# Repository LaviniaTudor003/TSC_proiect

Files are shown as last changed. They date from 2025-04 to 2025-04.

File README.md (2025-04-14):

# e-book reader



# BOM (Bill Of Materials)

| Component | Supplier Link | Datasheet |
|---|---|---|
| 744043680 | [Model](https://ro.mouser.com/ProductDetail/Wurth-Elektronik/744043680?qs=PGXP4M47uW6VkZq%252BkzjrHA%3D%3D) | [Datasheet](https://www.we-online.com/components/products/datasheet/744043680.pdf) |
| BD5229G-TR | [Model](https://www.digikey.ee/en/models/658502) | [Datasheet](https://www.rohm.com/datasheet?p=BD5229G&dist=Digi-key&media=referral&source=digi-key.com&campaign=Digi-key) |
| Capacitor 0402 | [Model](https://componentsearchengine.com/part-view/CC0402MRX5R5BB106/YAGEO) | [Datasheet](https://componentsearchengine.com/Datasheets/2/CC0402MRX5R5BB106.pdf) |
| CPH3225A | [Model](https://www.snapeda.com/parts/CPH3225A/Seiko+Instruments/view-part/?ref=eda) | [Datasheet](https://www.snapeda.com/parts/CPH3225A/Seiko%20Instruments/datasheet/) |
| Custom Button | [Model](https://industry.panasonic.com/global/en/products/control/switch/light-touch/number/evqpuj02k) | [Datasheet](https://industry.panasonic.com/global/en/downloads?tab=catalog&small_g_cd=203&part_no=EVQPUJ02K) |
| MBR0530 Schottky Diode | [Model](https://www.snapeda.com/parts/MBR0530/Onsemi/view-part/?ref=eda) | [Datasheet](https://www.snapeda.com/parts/MBR0530/ON%20Semiconductor/datasheet/) |
| PGB1010603MR | [Model](https://www.snapeda.com/parts/PGB1010603MR/Littelfuse/view-part/?ref=eda) | [Datasheet](https://www.snapeda.com/parts/PGB1010603MR/Littelfuse%20Inc./datasheet/) |
| QWIIC Connector | [Model](https://www.snapeda.com/parts/PRT-14417/SparkFun/view-part/) | [Datasheet](https://www.snapeda.com/parts/PRT-14417/SparkFun%20Electronics/datasheet/) |
| USB4110-GF-A | [Model](https://componentsearchengine.com/part-view/USB4110-GF-A/GCT%20(GLOBAL%20CONNECTOR%20TECHNOLOGY)) | [Datasheet](https://gct.co/files/drawings/usb4110.pdf) |
| USBLC6-2SC6Y | [Model](https://www.snapeda.com/parts/USBLC6-2SC6Y/STMicroelectronics/view-part/?ref=eda) | [Datasheet](https://www.snapeda.com/parts/USBLC6-2SC6Y/STMicroelectronics/datasheet/) |
| W25Q512JVEIQ | [Model](https://www.digikey.ro/en/models/10244706) | [Datasheet](https://www.winbond.com/resource-files/W25Q512JV%20SPI%20RevB%2006252019%20KMS.pdf) |
| RCL CPOL 3528 | [Model](https://www.snapeda.com/parts/TAJB475K025RNJ/AVX/view-part/?ref=dk&t=capacitor%203528&con_ref=None) | [Datasheet](https://s3.amazonaws.com/snapeda/datasheet/TAJB475K025RNJ_AVX.pdf) |
| DS3231SN | [Model](https://www.snapeda.com/parts/DS3231SN%23/Analog+Devices/view-part/?ref=eda) | [Datasheet](https://www.snapeda.com/parts/DS3231SN%23/Analog%20Devices/datasheet/) |
| ESP32 WROVER 0805 Capacitor  | [Model](https://ro.mouser.com/ProductDetail/KYOCERA-AVX/SD0805S020S1R0?qs=jCA%252BPfw4LHbpkAoSnwrdjw%3D%3D) | [Datasheet](https://ro.mouser.com/datasheet/2/40/schottky-3165252.pdf) |
| ESP32 WROVER BME680 Sensor | [Model](https://www.digikey.ro/en/models/7401317) | [Datasheet](https://www.bosch-sensortec.com/media/boschsensortec/downloads/datasheets/bst-bme680-ds001.pdf) |
| ESP32 WROVER MCP73831 Power Management | [Model](https://www.snapeda.com/parts/MCP73831T-2ACI/OT/Microchip/view-part/) | [Datasheet](https://www.snapeda.com/parts/MCP73831T-2ACI/OT/Microchip/datasheet/) |
| ESP32C6 Varistor 1812 | [Model](https://www.snapeda.com/parts/RC0603JR-070RL/Yageo/view-part/) | [Datasheet](https://www.snapeda.com/parts/RC0603JR-070RL/Yageo/datasheet/) |
| ESP32C6 WROOM-1-N8 | [Model](https://www.snapeda.com/parts/ESP32-C6-WROOM-1-N8/Espressif+Systems/view-part/?ref=eda) | [Datasheet](https://www.snapeda.com/parts/ESP32-C6-WROOM-1-N8/Espressif%20Systems/datasheet/) |
| FH34SRJ-24S-0.5SH | [Model](https://www.snapeda.com/parts/FH34SRJ-24S-0.5SH(99)/Hirose/view-part/) | [Datasheet](https://www.snapeda.com/parts/FH34SRJ-24S-0.5SH(99)/Hirose%20Connector/datasheet/) |
| LED Chip 0603 | [Model](https://grabcad.com/library/0603-smd-led-1) | [Datasheet](https://www.snapeda.com/parts/KP-1608SURCK/Kingbright/datasheet/) |
| MAX17048G+T10 | [Model](https://www.snapeda.com/parts/MAX17048G+T10/Analog+Devices/view-part/?ref=eda) | [Datasheet](https://www.snapeda.com/parts/MAX17048G+T10/Analog%20Devices/datasheet/) |
| Resistor 0402 | [Model](https://componentsearchengine.com/part-view/R0402%201%25%20100%20K%20(RC0402FR-07100KL)/YAGEO) | [Datasheet](https://www.yageo.com/upload/media/product/products/datasheet/rchip/PYu-RC_Group_51_RoHS_L_12.pdf) |
| 112A-TAAR-R03 | [Model](https://www.snapeda.com/parts/112A-TAAR-R03/Attend/view-part/) | [Datasheet](https://www.snapeda.com/parts/112A-TAAR-R03/Attend/datasheet/) |
| SI1308EDL-T1-GE3 MOSFET | [Model](https://www.snapeda.com/parts/SI1308EDL-T1-GE3/Vishay+Siliconix/view-part/?ref=eda) | [Datasheet](https://www.snapeda.com/parts/SI1308EDL-T1-GE3/Vishay%20Siliconix/datasheet/) |
| SJ | [Model](https://grabcad.com/library/solder-jumpers-1) | [Datasheet](https://github.com/TeodorStamatin/EBook_Reader/tree/main) |
| XC6220A331MR-G | [Model](https://componentsearchengine.com/part-view/XC6220A331MR-G/Torex) | [Datasheet](https://product.torexsemi.com/system/files/series/xc6220.pdf) |

# Conexiuni și module hardware utilizate:
•	USB-C Connector + ESD Protection
-	Intrare principală de alimentare și programare.
•	LDO Voltage Regulator
-	Reglează tensiunea de intrare la 3.3V stabil pentru alimentarea ESP32 și altor componente.
•	Li-Po Battery Charging Controller
-	Încarcă un acumulator Li-Po de la 5V (USB)
•	ESP32-C6
-	Microcontroller principal - responsabil de control, procesare si comunicare
•	E-Paper Drive Circuit
-	Oferă semnalul de putere necesar pentru activarea e-paper-ului
•	Display Type Selector
-	Permite comutarea
•	Voltage Supervisor + Reset
-	Asigură resetul corect la pornire
Poziționarea componentelor a fost gândită pentru:
•	acces facil la butoane,
•	vizibilitatea e-paper-ului,
•	montarea sigură a bateriei cu suport mecanic.
(pe baza schemei si recomandarilor primite)

# Functionalitate Hardware:
**Componente, Module și Senzori**
**Alimentare și Management Energie**
 Conector USB-C + Protecție ESD
 Funcție: Asigură alimentarea principală a sistemului și protejează împotriva descărcărilor electrostatice.
 
 Controler Încărcare Baterie – MCP73831
 Funcție: Gestionează încărcarea bateriei Li-Po, controlează curentul de încărcare.
 
 Baterie Li-Po
 Funcție: Sursă de alimentare secundară pentru funcționare autonomă (fără USB).
 
 Regulator de Tensiune LDO (3.3V)
 Funcție: Stabilizează tensiunea de alimentare pentru microcontroler și restul componentelor.
 
 Supervizor Tensiune + Buton Reset/Boot
 Funcție: Monitorizează nivelul tensiunii de alimentare și permite resetarea sau intrarea în modul boot al ESP32-C6.

**Control și Procesare:**
 ESP32-C6-WROOM-1-N8
 Funcție: Microcontroler principal. Gestionează comunicațiile (SPI, I2C, UART), interacțiunea cu senzorii și controlul perifericelor. Oferă conectivitate Wi-Fi și Bluetooth Low Energy.
 
 Memorie Externă NOR Flash – 64MB
 Funcție: Stocare extinsă pentru firmware și date.
 Interfață: SPI.

**Timp Real:**
 Modul RTC – DS3231SN
 Funcție: Ceas de timp real de înaltă precizie, cu suport pentru alarmă și funcționare pe baterie de backup.
 Interfață: I2C.

**Senzori de Mediu:**
 BME688 – Senzor ambiental
 Funcție: Măsoară temperatura, umiditatea, presiunea atmosferică și compușii organici volatili (VOC).
 Interfață: I2C (Qwiic / Stemma QT pentru conectare rapidă).
 Consum: Standby ultra-low power, activ ~3.1 mA.

**Afișaj:**
 Circuit de control pentru ecran E-Paper + Header de conectare
 Funcție: Generează semnalele necesare pentru funcționarea ecranelor E-Paper.
 Interfață: SPI cu linii de control dedicate (Busy, Reset, DC, CS).

**Stocare locală:**
 Slot Card microSD
 Funcție: Permite salvarea datelor local (loguri, configurări, fișiere).
 Interfață: SPI, cu semnal Chip Select dedicat.

**Interfețe de Comunicație:**
 I2C: Utilizat pentru BME688 și DS3231SN.
 SPI: Utilizat pentru NOR Flash, E-Paper Display și Card SD.
 UART: Disponibil pentru debug sau extensii opționale.
 Wi-Fi & Bluetooth LE: Oferite de modulul ESP32-C6.
# Pini ESP32-C6

| Componenta / Rol | Pin ESP32-C6 | Motivație |
|---|---|---|
| I2C SDA către BME688 și DS3231SN | IO14 (SDA) | Transmite date între microcontroler și dispozitivele I2C. |
| I2C SCL către BME688 și DS3231SN | IO15 (SCL) | Coordonează sincronizarea comunicării I2C. |
| SPI MOSI către NOR Flash, E-Paper, SD Card | IO6 (MOSI) | Trimite informații din ESP32 către perifericele conectate pe SPI. |
| SPI MISO din NOR Flash, E-Paper, SD Card | IO7 (MISO) | Primește date înapoi de la dispozitivele SPI. |
| SPI Clock | IO8 (SCK) | Oferă impulsurile de sincronizare pentru magistrala SPI. |
| Chip Select NOR Flash | IO9 (CS1) | Activează memoria NOR atunci când este utilizată. |
| Chip Select E-Paper Display | IO10 (CS2) | Selectează modulul de afișaj E-Paper pentru transmiterea de date. |
| Chip Select SD Card | IO11 (CS3) | Indică faptul că SD Card-ul este dispozitivul activ pe SPI. |
| UART RX, TX (debug) | IO16, IO17 | Permite trimiterea și recepționarea datelor pentru depanare și upload firmware. |
| Reset / Boot control | IO21 | Folosit pentru repornirea manuală a sistemului sau inițierea modului de programare. |

# PCB_2D:



# PCB_3D:
 


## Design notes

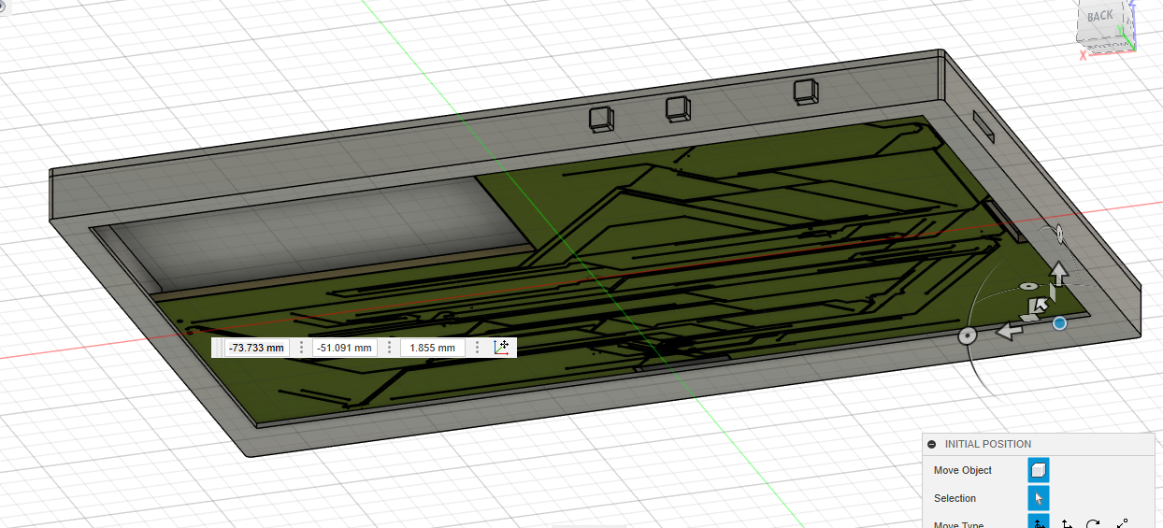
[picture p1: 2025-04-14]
Images/Screenshot 2025-04-14 131702.png

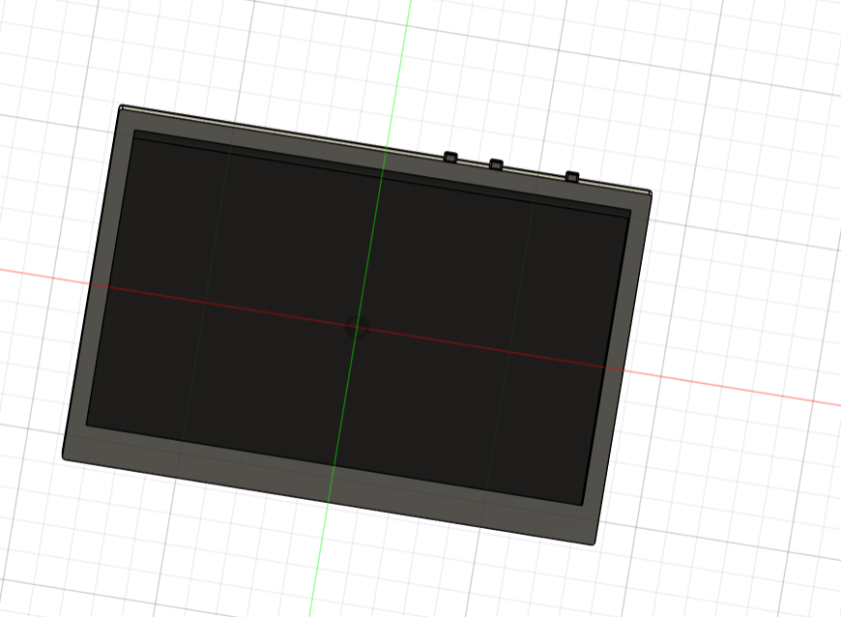
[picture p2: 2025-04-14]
Images/Screenshot 2025-04-14 134810.png

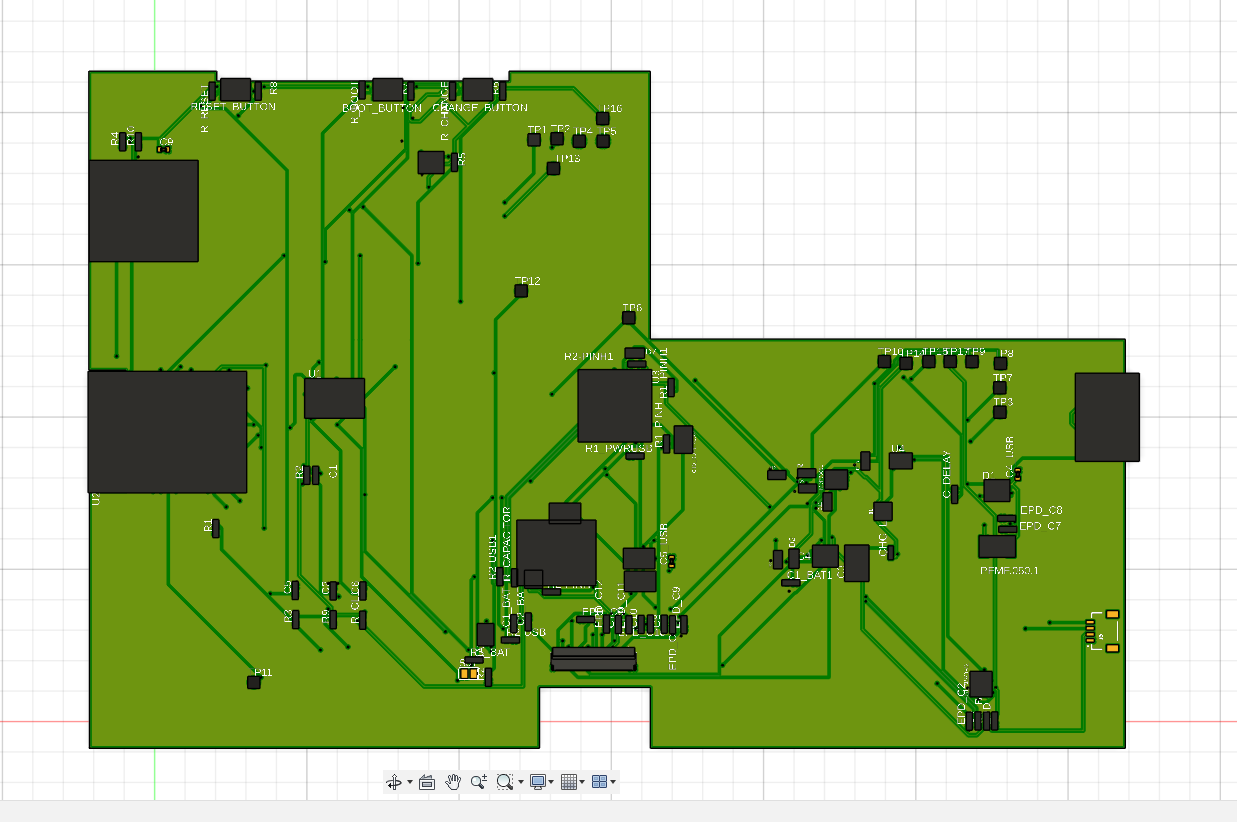
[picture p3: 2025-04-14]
Images/Screenshot 2025-04-14 090113.png

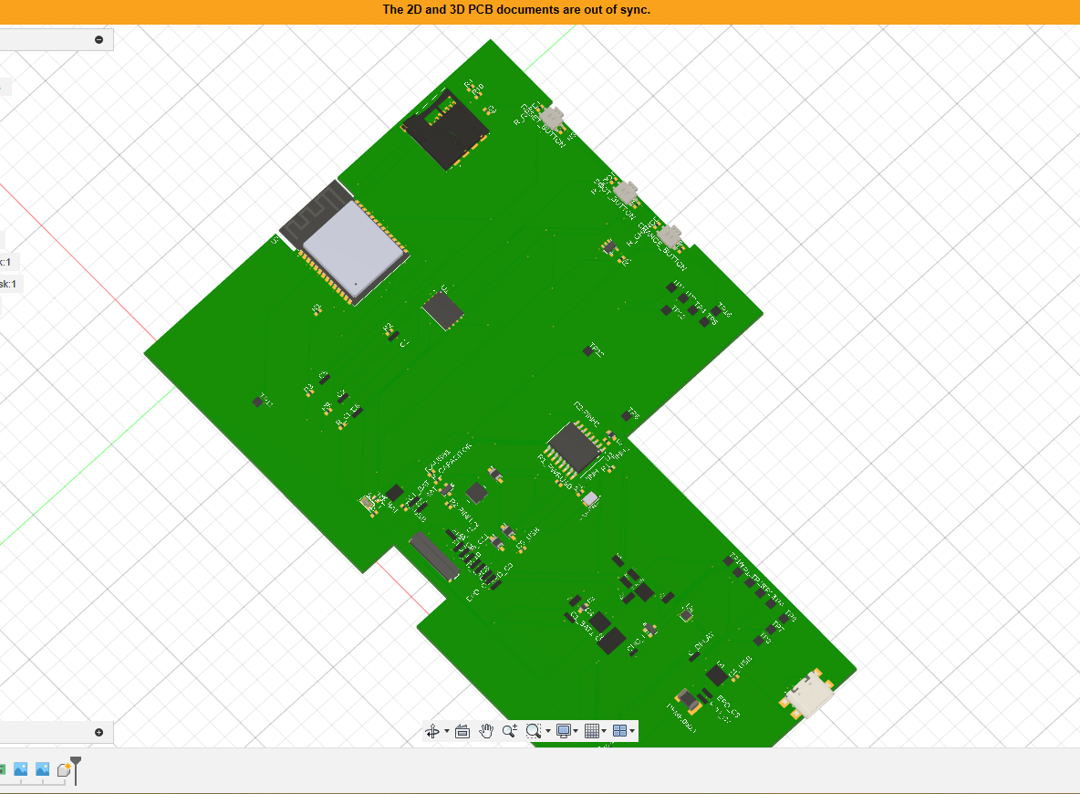
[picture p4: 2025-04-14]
Images/Screenshot 2025-04-14 125641.png

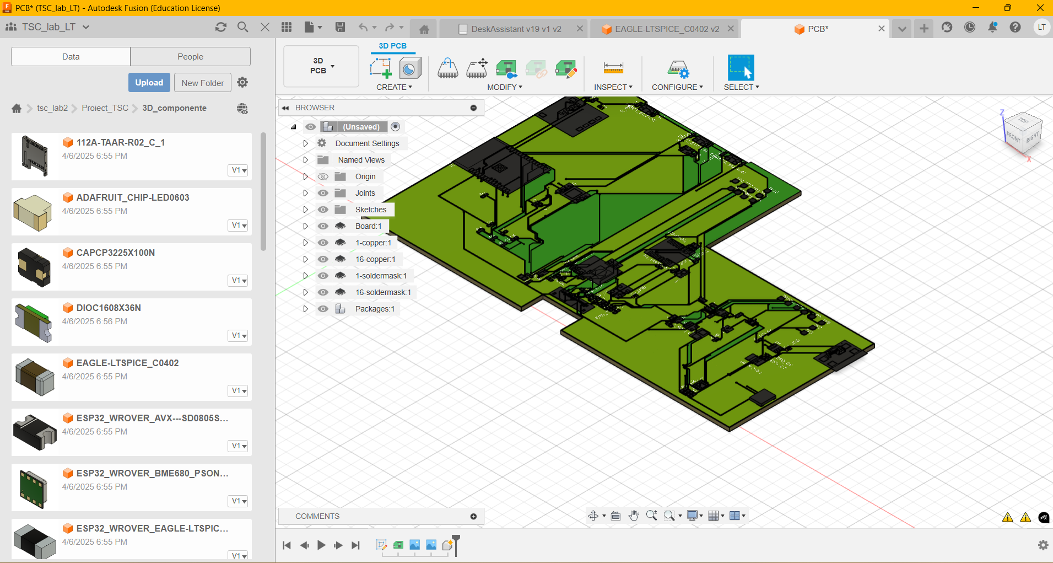
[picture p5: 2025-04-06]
Images/Screenshot 2025-04-06 190523.png

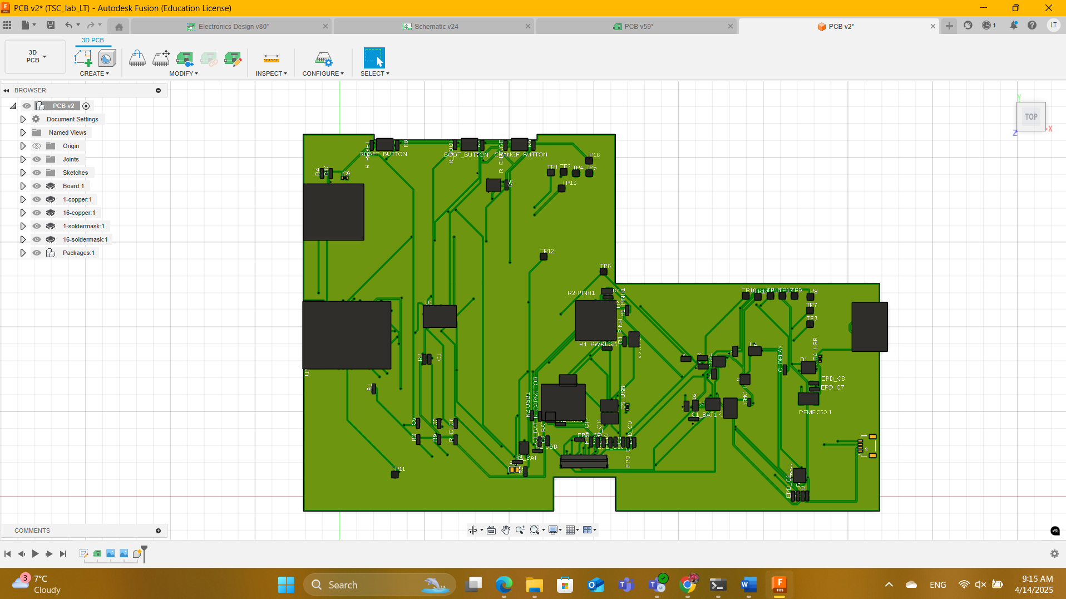
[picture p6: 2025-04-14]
Images/Screenshot 2025-04-14 091606.png

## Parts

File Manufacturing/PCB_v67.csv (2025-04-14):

Qty | Value | Device | Package | Parts | Description | ARROW_PART_NUMBER | ARROW_PRICE-STOCK | AVAILABILITY | CENTROID_NOT_SPECIFIED | CHECK_PRICES | COPYRIGHT | DATASHEET | DESCRIPTION | DIGIKEY_DESCRIPTION | DIGIKEY_PART_NUMBER | HEIGHT | LEAD_FREE | MANUFACTURER_NAME | MANUFACTURER_PART_NUMBER | MF | MFR_NAME | MOUSER_PART_NUMBER | MOUSER_PRICE-STOCK | MOUSER_TESTING_PART_NUMBER | MOUSER_TESTING_PRICE-STOCK | MP | MPN | PACKAGE | POPULARITY | PREFIX | PRICE | PROD_ID | PURCHASE-URL | ROHS | SNAPEDA_LINK | SPICEMODEL | SPICEPREFIX | TEMPERATURE_RANGE_HIGH | TEMPERATURE_RANGE_LOW | TP_SIGNAL_NAME | VALUE
1 |  | ADAFRUIT_LEDCHIP-LED0603 | ADAFRUIT_CHIP-LED0603 | CHG_LED | LED
2 |  | ESP32_WROVER_EAGLE-LTSPICE_RR0402 | ESP32_WROVER_EAGLE-LTSPICE_R0402 | R1, R2 | RESISTOR, European symbol |  |  |  |  |  |  |  |  |  |  |  |  |  |  |  |  |  |  |  |  |  |  |  |  |  |  |  |  |  |  | NONE | R
1 |  | SJ | SJ | SJ1 | SMD solder JUMPER |  |  |  |  |  |  |  |  |  |  |  |  |  |  |  |  |  |  |  |  |  |  |  | 3
1 | 0.1uF/50V | ESP32_WROVER_EAGLE-LTSPICE_CC0402 | ESP32_WROVER_EAGLE-LTSPICE_C0402 | EPD_C5 | CAPACITOR, European symbol |  |  |  |  |  |  |  |  |  |  |  |  |  |  |  |  |  |  |  |  |  |  |  |  |  |  |  |  |  |  | NONE | C
1 | 0.47 | ESP32_WROVER_EAGLE-LTSPICE_RR0402 | ESP32_WROVER_EAGLE-LTSPICE_R0402 | R3 | RESISTOR, European symbol |  |  |  |  |  |  |  |  |  |  |  |  |  |  |  |  |  |  |  |  |  |  |  |  |  |  |  |  |  |  | NONE | R
1 | 100k | ESP32_WROVER_EAGLE-LTSPICE_RR0402 | ESP32_WROVER_EAGLE-LTSPICE_R0402 | R1_PWRUSB | RESISTOR, European symbol |  |  |  |  |  |  |  |  |  |  |  |  |  |  |  |  |  |  |  |  |  |  |  |  |  |  |  |  |  |  | NONE | R
2 | 100nF | EAGLE-LTSPICE_CC0402 | EAGLE-LTSPICE_C0402 | C4_USB, C9 | CAPACITOR, European symbol |  |  |  |  |  |  |  |  |  |  |  |  |  |  |  |  |  |  |  |  |  |  |  |  |  |  |  |  |  |  | NONE | C
6 | 100nF | ESP32_WROVER_EAGLE-LTSPICE_CC0402 | ESP32_WROVER_EAGLE-LTSPICE_C0402 | C1, C2, C6, C8, C10, C_DELAY | CAPACITOR, European symbol |  |  |  |  |  |  |  |  |  |  |  |  |  |  |  |  |  |  |  |  |  |  |  |  |  |  |  |  |  |  | NONE | C
1 | 100uF TANT | RCL_CPOL-EUCT3528 | RCL_CT3528 | C3 | POLARIZED CAPACITOR, European symbol |  |  |  |  |  |  |  |  |  |  |  |  |  |  |  |  |  |  |  |  |  |  |  | 0 |  |  |  |  |  |  |  | C
15 | 10K | ESP32_WROVER_EAGLE-LTSPICE_RR0402 | ESP32_WROVER_EAGLE-LTSPICE_R0402 | R1_PINH, R1_PINH1, R2-PINH, R2-PINH1, R4, R5, R6, R7, R8, R9, R10, R_BOOT, R_CHANGE, R_CL1, R_RESET | RESISTOR, European symbol |  |  |  |  |  |  |  |  |  |  |  |  |  |  |  |  |  |  |  |  |  |  |  |  |  |  |  |  |  |  | NONE | R
1 | 10uF | ESP32_WROVER_EAGLE-LTSPICE_CC0402 | ESP32_WROVER_EAGLE-LTSPICE_C0402 | C7 | CAPACITOR, European symbol |  |  |  |  |  |  |  |  |  |  |  |  |  |  |  |  |  |  |  |  |  |  |  |  |  |  |  |  |  |  | NONE | C
1 | 112A-TAAR-R03_ATTEND | 112A-TAAR-R03_ATTEND | 112ATAARR03ATTEND | J4 | Micro SD Card Socket, Push-Push Type, Top Mount, SMT, H=1.83mm, 10u |  |  |  |  |  |  |  | Micro SD Card Socket | Push-Push Type | Top Mount | SMT | H=1.83mm | 10u |  |  | 1.9mm |  | ATTEND | 112A-TAAR-R03 ATTEND
1 | 15 | ESP32_WROVER_EAGLE-LTSPICE_RR0402 | ESP32_WROVER_EAGLE-LTSPICE_R0402 | R_CAPACITOR | RESISTOR, European symbol |  |  |  |  |  |  |  |  |  |  |  |  |  |  |  |  |  |  |  |  |  |  |  |  |  |  |  |  |  |  | NONE | R
1 | 1uF | ESP32_WROVER_EAGLE-LTSPICE_CC0402 | ESP32_WROVER_EAGLE-LTSPICE_C0402 | C5 | CAPACITOR, European symbol |  |  |  |  |  |  |  |  |  |  |  |  |  |  |  |  |  |  |  |  |  |  |  |  |  |  |  |  |  |  | NONE | C
9 | 1uF/50V | ESP32_WROVER_EAGLE-LTSPICE_CC0402 | ESP32_WROVER_EAGLE-LTSPICE_C0402 | EPD_C1, EPD_C2, EPD_C6, EPD_C7, EPD_C8, EPD_C9, EPD_C10, EPD_C11, EPD_C12 | CAPACITOR, European symbol |  |  |  |  |  |  |  |  |  |  |  |  |  |  |  |  |  |  |  |  |  |  |  |  |  |  |  |  |  |  | NONE | C
1 | 200 | ESP32_WROVER_EAGLE-LTSPICE_RR0402 | ESP32_WROVER_EAGLE-LTSPICE_R0402 | R1_BAT | RESISTOR, European symbol |  |  |  |  |  |  |  |  |  |  |  |  |  |  |  |  |  |  |  |  |  |  |  |  |  |  |  |  |  |  | NONE | R
2 | 20V/4.2A/52mO/1.4W | ESP32_WROVER_SPARKFUN-DISCRETESEMI_MOSFET_PCH-DMG2305UX-7 | ESP32_WROVER_SPARKFUN-DISCRETESEMI_SOT23-3 | Q1, Q2 | P-channel MOSFETs |  |  |  |  |  |  |  |  |  |  |  |  |  |  |  |  |  |  |  |  |  |  |  |  |  |  | TRAN-14388 |  |  |  |  |  |  |  |  | 20V/4.2A/52mO/1.4W
1 | 2K | ESP32_WROVER_EAGLE-LTSPICE_RR0402 | ESP32_WROVER_EAGLE-LTSPICE_R0402 | R2_BAT | RESISTOR, European symbol |  |  |  |  |  |  |  |  |  |  |  |  |  |  |  |  |  |  |  |  |  |  |  |  |  |  |  |  |  |  | NONE | R
1 | 4.7uF | EAGLE-LTSPICE_CC0402 | EAGLE-LTSPICE_C0402 | C5_USB | CAPACITOR, European symbol |  |  |  |  |  |  |  |  |  |  |  |  |  |  |  |  |  |  |  |  |  |  |  |  |  |  |  |  |  |  | NONE | C
4 | 4.7uF | ESP32_WROVER_EAGLE-LTSPICE_CC0402 | ESP32_WROVER_EAGLE-LTSPICE_C0402 | C1_BAT, C1_BAT1, C1_BAT2, C2_BAT | CAPACITOR, European symbol |  |  |  |  |  |  |  |  |  |  |  |  |  |  |  |  |  |  |  |  |  |  |  |  |  |  |  |  |  |  | NONE | C
1 | 4.7uF/25V | ESP32_WROVER_EAGLE-LTSPICE_CC0402 | ESP32_WROVER_EAGLE-LTSPICE_C0402 | C4 | CAPACITOR, European symbol |  |  |  |  |  |  |  |  |  |  |  |  |  |  |  |  |  |  |  |  |  |  |  |  |  |  |  |  |  |  | NONE | C
2 | 5k1 | ESP32_WROVER_EAGLE-LTSPICE_RR0402 | ESP32_WROVER_EAGLE-LTSPICE_R0402 | R2-USB, R2-USB1 | RESISTOR, European symbol |  |  |  |  |  |  |  |  |  |  |  |  |  |  |  |  |  |  |  |  |  |  |  |  |  |  |  |  |  |  | NONE | R
1 | 744043680IND_4828-WE-TPC_WRE | 744043680IND_4828-WE-TPC_WRE | IND_4828-WE-TPC_WRE | L1 |  |  |  |  |  |  | Copyright (C) 2024 Ultra Librarian. All rights reserved. |  |  |  |  |  |  |  | 744043680 |  | Wurth Electronics
1 | BD5229G-TR | BD5229G-TR | SOT95P280X120-5N | IC1 | Voltage Detector with Adjustable Delay Time: CMOS processes are utilized to develop high precision, low current consumption CMOS reset ICs that allow arbitrary setting of the delay time. The extensive lineup includes both Nch Open Drain and CMOS output types in a wide range of detection voltages (from 2.3V to 6.0V, in 0.1V steps), enabling selection of the ideal solution based on customer requirements. In addition, the entire series is of course both lead-free and RoHS-compliant. |  |  |  |  |  |  |  | Voltage Detector with Adjustable Delay Time: CMOS processes are utilized to develop high precision | low current consumption CMOS reset ICs that allow arbitrary setting of the delay time. The extensive lineup includes both Nch Open Drain and CMOS output types in a wide range of detection voltages (from 2.3V to 6.0V | in 0.1V steps) | enabling selection of the ideal solution based on customer requirements. In addition | the entire series is of course both lead-free and RoHS-compliant. |  |  | 1.25mm |  | ROHM Semiconductor | BD5229G-TR |  |  | 755-BD5229G-TR | https://www.mouser.co.uk/ProductDetail/ROHM-Semiconductor/BD5229G-TR?qs=4kLU8WoGk0vvnhrrYwdszw%3D%3D
1 | BME688 | ESP32_WROVER_BME680_BME680 | ESP32_WROVER_BME680_PSON80P300X300X100-8N | SENSOR2 | Integrated Environmental Unit |  |  | Unavailable |  |  |  |  | Integrated Environmental Unit |  |  |  |  |  |  | Bosch Sensortec |  |  |  |  |  | BME680 |  | LGA-8 Bosch Tools |  |  | None
3 | BUTTON_CUSYOMV1 | BUTTON_CUSYOMV1 | MYBUTTON | BOOT_BUTTON, CHANGE_BUTTON, RESET_BUTTON
1 | CPH3225A | CPH3225A | CAPCP3225X100N | C10_SUPERCAP | Cap 0.011F 3.3V 1210 Flat Check availability |  |  | Not in stock |  | https://www.snapeda.com/parts/CPH3225A/Seiko+Instruments/view-part/?ref=eda |  |  | 11 mF (EDLC) Supercapacitor 3.3 V 1210 (3225 Metric) - - |  |  |  |  |  |  | Seiko Instruments |  |  |  |  |  | CPH3225A |  | 1210 Seiko |  |  | None |  | https://www.snapeda.com/api/url_track_click_mouser/?unipart_id=562593&manufacturer=Seiko Instruments&part_name=CPH3225A&search_term=None |  | https://www.snapeda.com/parts/CPH3225A/Seiko+Instruments/view-part/?ref=snap
1 | DS3231SN# | DS3231SN# | SOIC127P1032X265-16N | U3 | Real Time Clock Serial 16-Pin SOIC W T/R Check availability |  |  | In Stock |  | https://www.snapeda.com/parts/DS3231SN%23/Analog+Devices/view-part/?ref=eda |  |  | Extremely Accurate I²C-Integrated RTC/TCXO/Crystal |  |  |  |  |  |  | Analog Devices |  |  |  |  |  | DS3231SN# |  | SOIC-16 Maxim |  |  | None |  | https://www.snapeda.com/api/url_track_click_mouser/?unipart_id=99048&manufacturer=Analog Devices&part_name=DS3231SN#&search_term=None |  | https://www.snapeda.com/parts/DS3231SN%23/Analog+Devices/view-part/?ref=snap
1 | ESP32-C6-WROOM-1-N8 | ESP32-C6-WROOM-1-N8 | XCVR_ESP32-C6-WROOM-1-N8 | U2 | Check availability |  |  | In Stock |  | https://www.snapeda.com/parts/ESP32-C6-WROOM-1-N8/Espressif+Systems/view-part/?ref=eda |  |  | Multiprotocol Modules ESP32-C6 module | Wi-Fi 6 in 2.4 GHz band | Bluetooth 5 | Zigbee 3.0 and Thread. ESP34-WROOM Compatible - ENGINEERING SAMPLE |  |  |  |  |  |  | Espressif Systems |  |  |  |  |  | ESP32-C6-WROOM-1-N8 |  | None |  |  | None |  |  |  | https://www.snapeda.com/parts/ESP32-C6-WROOM-1-N8/Espressif+Systems/view-part/?ref=snap
1 | ESP32C6_VARISTORCN1812 | ESP32C6_VARISTORCN1812 | ESP32C6_VARISTOR_CT/CN1812 | PFMF.050.1 | VARISTOR |  |  |  |  |  |  |  |  |  |  |  |  |  |  |  |  |  |  |  |  |  |  |  | 0
2 | ESP32_WROVER_AVX---SD0805S020S1R0_AVX_SD0805S020S1R0_0_0AVX_SD0805S020S1R0_0_0 | ESP32_WROVER_AVX---SD0805S020S1R0_AVX_SD0805S020S1R0_0_0AVX_SD0805S020S1R0_0_0 | ESP32_WROVER_AVX---SD0805S020S1R0_AVX_SD0805S020S1R0_0 | D2, D7 | Schottky Barrier Rectifier Diode |  |  |  | No |  |  | http://datasheets.avx.com/schottky.pdf |  | DIODE SCHOTTKY 20V 1A 0805 | 478-7800-1-ND |  | yes |  |  | AVX |  | 581-SD0805S020S1R0 |  |  |  |  |  | 0805 (2012 metric) |  | D |  |  |  | yes |  |  |  | +125°C | -55°C
1 | ESP32_WROVER_SPARKFUN-IC-POWER_MCP73831 | ESP32_WROVER_SPARKFUN-IC-POWER_MCP73831 | ESP32_WROVER_SPARKFUN-IC-POWER_SOT23-5 | MCP73831 | MCP73831T Li-Ion, Li-Pol Controller |  |  |  |  |  |  |  |  |  |  |  |  |  |  |  |  |  |  |  |  |  |  |  |  |  |  | IC-09995
1 | FH34SRJ-24S-0.5SH_99_ | FH34SRJ-24S-0.5SH_99_ | FH34SRJ24S05SH99 | J2 | (0.50mm) Surface Mount, Right Angle |  |  |  |  |  |  |  | 24 Position FFC | FPC Connector Contacts | (0.50mm) Surface Mount | Right Angle |  |  | 1.1mm |  | Hirose | FH34SRJ-24S-0.5SH(99) |  |  | 798-FH34SRJ24S05SH99 | https://www.mouser.co.uk/ProductDetail/Hirose-Connector/FH34SRJ-24S-0.5SH99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
1 | MAX17048G+T10 | MAX17048G+T10 | SON50P200X200X80-9N | U4 | Check availability |  |  | In Stock |  | https://www.snapeda.com/parts/MAX17048G+T10/Analog+Devices/view-part/?ref=eda |  |  | 3µA 1-Cell/2-Cell Fuel Gauge with ModelGauge |  |  |  |  |  |  | Analog Devices |  |  |  |  |  | MAX17048G+T10 |  | TDFN-8 Maxim |  |  | None |  | https://www.snapeda.com/api/url_track_click_mouser/?unipart_id=329239&manufacturer=Analog Devices&part_name=MAX17048G+T10&search_term=None |  | https://www.snapeda.com/parts/MAX17048G+T10/Analog+Devices/view-part/?ref=snap
3 | MBR0530 | MBR0530 | SOD3716X135N | D3, D4, D5 | ON SEMICONDUCTOR - MBR0530 - DIODE, SCHOTTKY, 0.5A, 30V, SOD-123 |  |  | In Stock |  | https://www.snapeda.com/parts/MBR0530/Onsemi/view-part/?ref=eda |  |  | Diode Schottky 30 V 500mA Surface Mount SOD-123 |  |  |  |  |  |  | ON Semiconductor |  |  |  |  |  | MBR0530 |  | SOD-123-2 ON Semiconductor |  |  | None |  | https://www.snapeda.com/api/url_track_click_mouser/?unipart_id=179458&manufacturer=ON Semiconductor&part_name=MBR0530&search_term=None |  | https://www.snapeda.com/parts/MBR0530/Onsemi/view-part/?ref=snap
6 | PGB1010603MR | PGB1010603MR | DIOC1608X36N | D6, D8, D9, D10, D11, D12 | Check availability |  |  | In Stock |  | https://www.snapeda.com/parts/PGB1010603MR/Littelfuse/view-part/?ref=eda |  |  | 150V (Typ) Clamp - Ipp Tvs Diode Surface Mount 0603 (1608 Metric) |  |  |  |  |  |  | Littelfuse Inc. |  |  |  |  |  | PGB1010603MR |  | 0603 Littelfuse Inc. |  |  | None |  | https://www.snapeda.com/api/url_track_click_mouser/?unipart_id=5659453&manufacturer=Littelfuse Inc.&part_name=PGB1010603MR&search_term=None |  | https://www.snapeda.com/parts/PGB1010603MR/Littelfuse/view-part/?ref=snap
1 | QWIIC_RIGHT_ANGLE | QWIIC_CONNECTORJS-1MM | JST04_1MM_RA | J3 | SparkFun I2C Standard Qwiic Connector |  |  |  |  |  |  |  |  |  |  |  |  |  |  |  |  |  |  |  |  |  |  |  |  |  |  | CONN-13694 |  |  |  |  |  |  |  |  | QWIIC_RIGHT_ANGLE
1 | SAMACSYS_PARTS_USB4110-GF-A | SAMACSYS_PARTS_USB4110-GF-A | SAMACSYS_PARTS_USB4110GFA | J1 | CONN USB 2.0 TYPE-C R/A SMT |  |  |  |  |  |  |  | CONN USB 2.0 TYPE-C R/A SMT |  |  | 3.26mm |  | GCT (GLOBAL CONNECTOR TECHNOLOGY) | USB4110-GF-A |  |  | 640-USB4110-GF-A | https://www.mouser.co.uk/ProductDetail/GCT/USB4110-GF-A?qs=KUoIvG%2F9IlYiZvIXQjyJeA%3D%3D
1 | SI1308EDL-T1-GE3 | SI1308EDL-T1-GE3 | SOT65P210X110-3N | Q3 | MOSFET N-Ch 30V 1.5A TrenchFET SC70 Vishay Si1308EDL-T1-GE3 N-channel MOSFET Transistor, 1.5 A, 30 V, 3-Pin SC-70 |  |  | In Stock |  | https://www.snapeda.com/parts/SI1308EDL-T1-GE3/Vishay+Siliconix/view-part/?ref=eda |  |  | Si1308EDL-T1-GE3 N-channel MOSFET Transistor | 1.5 A | 30 V | 3-Pin SC-70 | Siliconix / Vishay SI1308EDL-T1-GE3 |  |  |  |  |  |  | Vishay Siliconix |  |  |  |  |  | SI1308EDL-T1-GE3 |  | SOT-323 Vishay Semiconductor |  |  | None |  | https://www.snapeda.com/api/url_track_click_mouser/?unipart_id=274603&manufacturer=Vishay Siliconix&part_name=SI1308EDL-T1-GE3&search_term=None |  | https://www.snapeda.com/parts/SI1308EDL-T1-GE3/Vishay+Siliconix/view-part/?ref=snap
17 | TPTP20R | TPTP20R | TP20R | TP1, TP2, TP3, TP4, TP5, TP6, TP7, TP8, TP9, TP10, TP11, TP12, TP13, TP14, TP15, TP16, TP17 | Test pad |  |  |  |  |  |  |  |  |  |  |  |  |  |  |  |  |  |  |  |  |  |  |  | 2
1 | USBLC6-2SC6Y | USBLC6-2SC6Y | SOT95P280X145-6N | D1 | Low Cap. ESD Protection Auto SOT-23-6 STMicroelectronics USBLC6-2SC6Y, Dual Uni-Directional TVS Diode Array, 6-Pin SOT-23 |  |  | In Stock |  | https://www.snapeda.com/parts/USBLC6-2SC6Y/STMicroelectronics/view-part/?ref=eda |  |  | 17V Clamp 5A (8/20µs) Ipp Tvs Diode Surface Mount SOT-23-6 |  |  |  |  |  |  | STMicroelectronics |  |  |  |  |  | USBLC6-2SC6Y |  | SOT-23-6 STMicroelectronics |  |  | None |  |  |  | https://www.snapeda.com/parts/USBLC6-2SC6Y/STMicroelectronics/view-part/?ref=snap
1 | W25Q512JVEIQ | W25Q512JVEIQ | SON127P600X800X80-9N | U1 | Check availability |  |  | In Stock |  | https://www.snapeda.com/parts/W25Q512JVEIQ/Winbond+Electronics/view-part/?ref=eda |  |  | FLASH - NOR Memory IC 512Mb (64M x 8) SPI - Quad I/O 133 MHz 8-WSON (8x6) |  |  |  |  |  |  | Winbond Electronics |  |  |  |  |  | W25Q512JVEIQ |  | Package |  |  | None |  |  |  | https://www.snapeda.com/parts/W25Q512JVEIQ/Winbond+Electronics/view-part/?ref=snap
1 | XC6220A331MR-G | XC6220A331MR-G | SOT95P280X120-5N | IC4 | LDO Voltage Regulators |  |  |  |  |  |  |  | LDO Voltage Regulators |  |  | 1.2mm |  | Torex | XC6220A331MR-G |  |  | 865-XC6220A331MR-G | https://www.mouser.co.uk/ProductDetail/Torex-Semiconductor/XC6220A331MR-G?qs=AsjdqWjXhJ8ZSWznL1J0gg%3D%3D

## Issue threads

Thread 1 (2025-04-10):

Format README nonconform

mariad765, 2025-04-10:
### ❗ Format incorect al fișierului README

Fișierul încărcat nu respectă cerințele specificate în enunț.
Se solicită un fișier README.md (format Markdown), însă a fost încărcat un fișier în format .docx.

📎 Fișier încărcat: README.docx
📄 Format cerut: README.md

#### 📷 Capturi relevante

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

### 💡 Recomandare

Recomand să convertesti fișierul .docx în format Markdown (.md) și să îl încarci din nou cu numele README.md, astfel încât să fie corect afișat în interfața GitHub și să respecte cerințele task-ului.

Closed 2025-04-12.

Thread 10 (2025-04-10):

Lipsa fisier .STEP

mariad765, 2025-04-10:
## ❗ Lipsă fișier .STEP

Am observat că fișierul .STEP nu este inclus în proiectul final. Acest fișier este esențial pentru schimbul de date între diferite platforme de design și pentru importul modelelor 3D în diverse aplicații CAD. Fișierul .STEP permite interacțiunea cu diverse instrumente de proiectare și prototipură, fiind standardul acceptat pentru modelare 3D în industrie. Fără acest fișier, procesul de validare, simulare și fabricare poate fi îngreunat.

## 💡 Recomandare
Îți recomand să adaugi fișierul .STEP pentru modelul 3D final al proiectului, astfel încât să poți:

-> Împărtăși designul cu alți membri ai echipei care pot folosi diferite aplicații CAD.

-> Importa și exporta modele 3D către și din alte platforme de design sau simulare.

-> A facilita prototipurarea și fabricarea rapidă a plăcii sau componentelor.

Asigură-te că exportul fișierului .STEP este realizat corect din softul tău de modelare 3D .

Closed 2025-04-14.

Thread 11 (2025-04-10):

Modelul 3D conține doar 2 componente

mariad765, 2025-04-10:
## ❗ Modelul 3D conține doar 2 capacitori

Am observat că modelul 3D final al proiectului conține doar 2 condensatori, în timp ce schema și designul PCB indică mai mulți condensatori care ar trebui să fie integrați în modelul 3D. Modelul 3D ar trebui să reflecte complet designul PCB, incluzând toate componentele din schematică și asigurându-se că sunt reprezentate corect.

### 📸

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

## 💡 Recomandare
Îți recomand să adaugi toate componentele micute precum diode, rezistente, capacitori, etc...
Verifică schema și asigură-te că toate condensatoarele (electrolitice, ceramice etc.) sunt incluse.

-> Modelează condensatoarele / orice alta pieca care trebuie inclusa corespunzătoare în 3D și poziționează-le corect pe PCB.

-> Verifică integritatea designului 3D pentru a te asigura că toate piesele sunt reprezentate conform cu layout-ul real.

Este important ca modelul 3D să fie cât mai fidel designului final pentru a preveni probleme la asamblare și integrare.

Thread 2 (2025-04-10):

Documentatie incompleta - lipsa BOM

mariad765, 2025-04-10:
# ❗ Probleme identificate la fișierul README

### ❗  Lipsă Bill of Materials (BOM)

Conform cerințelor proiectului, trebuia inclus un tabel care să detalieze Bill of Materials (BOM) — adică lista completă a componentelor utilizate în realizarea proiectului hardware. Nu a fost identificata nici o secțiune în README.md care să conțină BOM.

#### 📷 Capturi relevante

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

### 💡 Recomandare
 Recomand să adaugi un fișier numit BOM.md sau o secțiune în README.md cu următoarea structură:

## 📦 Bill of Materials (BOM)

| Componentă        | Link magazin        | Link datasheet           |
|------------------|-------------------|------------------------|
| Rezistor 10kΩ     | DidiKey                 | datasheet1|
| ESP32-C6         | DigiKey  | datasheet2 |
| Condensator 100nF | -                 | datasheet3     |

### ❗ Lipsa descriere pini

Nu am regăsit în proiect o secțiune dedicata care să descrie clar conexiunile pinilor între microcontroller și celelalte componente. Fără o descriere a pinilor, devine dificil pentru o altă persoană să înțeleagă schema de conectare sau să refacă montajul fizic.

#### 📷 Capturi relevante

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

### 💡 Recomandare

Îți recomand să adaugi o secțiune în README.md sau un fișier separat, numit pinout.md, care să conțină o tabelă clară cu toate conexiunile relevante.

Exemplu:

## 📌 Pinout

| Funcție           | Pin ESP32-C6 | Componentă conectată     |
|-------------------|--------------|---------------------------|
| LED de stare      | pin1        | LED                      |
| Senzor 1  | pin2       | Senzor capacitiv         |
| componenta 2      | pin3     | Releu                    |

Closed 2025-04-12.

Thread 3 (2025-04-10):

Lipsa BOM

mariad765, 2025-04-10:
### ❗ Lipsă fișier Bill of Materials (BOM)

Conform cerințelor proiectului, trebuia inclus un fișier care să detalieze Bill of Materials (BOM) — adică lista completă a componentelor utilizate în realizarea proiectului hardware. Nu a fost identificat niciun fișier dedicat care să conțină BOM.

###  📷 Capturi relevante

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

### 💡 Recomandare

Recomand urmarea pasilor de la https://jlcpcb.com/help/article/how-to-generate-bom-and-cpl-from-fusion360 pentru crearea unui fisier .bom. Acesta ar trebui introdus in proiect conform schemei ierarhice din captura de mai sus.

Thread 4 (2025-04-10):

Fisier CPL nonconform

mariad765, 2025-04-10:
### ❗ Format incorect al fișierului CPL

Este vorba strict de extensie. A fost incarcat un .csv in loc de un .cpl, asa cum este mentionat in task.

### 📷 Capturi relevante

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

Closed 2025-04-14.

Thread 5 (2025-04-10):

Lipsa Via Stiching

mariad765, 2025-04-10:
## ❗ Lipsă Via Stitching în designul PCB

Am observat că layout-ul plăcii de circuit nu include via stitching între planurile de masă sau între diferite straturi. Absența via stitching-ului poate duce la probleme atât din punct de vedere electric, cât și mecanic, în special în proiectele cu mai multe straturi sau frecvențe mai mari.

### 📸

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

### 💡 De ce este important via stitching:
#### 🔌 Stabilitate a planului de masă
Stitching vias conectează planurile de GND de pe straturi diferite, asigurând o conexiune solidă și reducând zgomotul electric. Acest lucru previne efecte precum ground bounce, care pot afecta integritatea semnalului.
🔗 [Sursa 1](https://www.globalwellpcba.com/stitching-vias-in-pcb-design/) • [Sursa 2](https://www.globalwellpcba.com/pcb-via-stitching/)

#### 🧱 Rezistență mecanică sporită
Prin conectarea straturilor între ele, via stitching-ul întărește fizic PCB-ul și îl face mai rezistent la șocuri și vibrații.

## ✅ Recomandare
Îți recomand să adaugi via stitching. In captura de ecran de mai sus am sugerat modul de adaugare.

Closed 2025-04-13.

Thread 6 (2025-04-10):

Erori nerezolvate în proiectul PCB

mariad765, 2025-04-10:
## ❗ Erori nerezolvate în proiectul PCB

Am identificat erori rămase nerezolvate în layout-ul plăcii de circuit imprimat. Acestea apar în zona validării designului și pot afecta funcționalitatea plăcii sau procesul de fabricație.

### 📸

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

Erorile par să fie generate de un footprint incorect atribuit unei componente — cel mai probabil, dimensiunile sau pad-urile nu corespund standardelor sau simbolului din schematică.

## 💡 Recomandare

Îți recomand să revizuiești și să modifici footprint-ul piesei respective pentru a corespunde cu:

* Simbolul din schematică

* Dimensiunile reale ale componentei (conform datasheet-ului)

* Regulile de DRC (Design Rule Check)

Poți edita footprint-ul existent sau înlocui componenta cu una din biblioteca oficială, adaptată pentru fabricație. Mai rapid ar fi editarea celui existent.

Closed 2025-04-14.

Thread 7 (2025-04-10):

Dimensiuni incorecte la traseele de putere

mariad765, 2025-04-10:
## ❗ Trasee de putere cu lățime incorectă (VUSB, VBUS, 3V3)

Am observat că mai multe trasee de putere din designul plăcii PCB (ex: VUSB, VBUS, 3V3) au o lățime de 0.127 mm, ceea ce nu respectă cerința minimă de 0.3 mm pentru trasee care transportă curent.
#### 🔌 Traseele de putere trebuie să fie suficient de late pentru a susține curentul necesar fără pierderi semnificative de tensiune sau încălzire excesivă.
#### 📏 Lățimea detectată: 0.127 mm
#### ✅ Lățimea minimă cerută pentru power routes: 0.3 mm

### 📍 Afectează următoarele linii:

-> VUSB

-> VBUS

-> 3V3

## 💡 Recomandare
Îți recomand să modifici lățimea traseelor respective astfel:

1) Deschide designul PCB în Fusion 360 (sau softul folosit).

2) Selectează traseele corespunzătoare liniilor de putere.

3) Modifică lățimea la minimum 0.3 mm — ideal chiar mai mare, în funcție de curentul estimat.

4) Re-rulează DRC (Design Rule Check) pentru a valida modificările.

#### 📸 Capturi

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

Closed 2025-04-13.

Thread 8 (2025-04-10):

PCB nedecupat pentru antena

mariad765, 2025-04-10:
### ❗ Lipsă decupaj pentru antena

Am observat că zona aferentă antenei modulului  nu este decupată corespunzător în layout-ul plăcii. Antena este acoperită parțial sau total de planuri de masă sau de trasee, ceea ce afectează performanța semnalului. Pentru modulele cu antene PCB integrate, producătorul recomandă un decupaj clar în jurul antenei pentru:

-> Reducerea interferențelor

-> Respectarea ghidurilor de layout din datasheet

### 📸

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

### 💡 Recomandare

Îți recomand să modifici designul astfel:

1) Elimină planurile de cupru (ex: GND) din zona antenei.

2) Adaugă un decupaj fizic (keep-out layer) în zona antenei, conform cu specificațiile modulului din datasheet.

3) Evită traseele și componentele în imediata apropiere a antenei.

Closed 2025-04-13.

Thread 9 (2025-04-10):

Lipsa model 3D  final

mariad765, 2025-04-10:
## ❗ Lipsă model 3D final cu baterie, carcasă și display

Am observat că modelul 3D final al proiectului nu include toate componentele esențiale, precum bateria, carcasa, display-ul, condensatoarele, rezistorii, diodele, test pad-urile și butoanele. Acestea sunt critice pentru evaluarea completă a designului și pentru verificarea integrității ansamblului hardware. Modelul 3D nu reflectă întregul sistem, ceea ce face imposibilă evaluarea corectă a următoarelor aspecte:

-> Dimensiunile fizice finale ale produsului (pentru integrarea componentelor)

-> Montajul și poziționarea corectă a componentelor

-> Compatibilitatea între carcasă și componentele electronice

-> Accesibilitatea pentru testare și depanare (prin includerea test pad-urilor și butoanelor)

## 💡 Recomandare

Îți recomand să adaugi următoarele componente în modelul 3D:

1) Bateria — include dimensiunile și locația exactă.

2) Carcasa — modelează carcasă completă, având în vedere accesibilitatea și protecția componentelor.

3) Display-ul — adaugă un model 3D al display-ului (LCD, OLED, etc.) cu detalii pentru integrarea sa.

4) Condensatoarele — include modelele corespunzătoare pentru toate condensatoarele utilizate în circuit.

5) Rezistorii — include modelele pentru rezistori și asigură-te că sunt poziționați corespunzător în cadrul designului.

6) Test pad-uri — include pad-uri de test pentru măsurători și depanare, astfel încât să poți verifica semnalele la diferite puncte ale circuitului.

7) Butoanele — include modelele pentru butoane (de tipul push-button sau toggle) și asigură-te că sunt ușor accesibile în carcasă pentru utilizatori.

Asigură-te că toate piesele sunt poziționate corect și că există suficient spațiu pentru conectarea lor fizică și electrică.

Closed 2025-04-14.

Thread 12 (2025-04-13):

PCB cu plan de masa incomplet

mariad765, 2025-04-13:
## Descriere:
Am observat că în proiectul tău, planurile de masă nu urmează corect conturul plăcii, similar cu problema întâmpinată în proiectul meu. Această problemă poate duce la erori de fabricație și integritate electrică.

### Recomandări:

- După modificări, rulează **Ratsnest** pentru a confirma că toate zonele au fost umplute corect și că nu mai există goluri neacoperite.

Deși ar putea funcționa și fără aceste modificări, îți recomand să urmezi aceste bune practici.

-> corectarea issue-ului necesita si corectari in screen captures si readme

Closed 2025-04-13.

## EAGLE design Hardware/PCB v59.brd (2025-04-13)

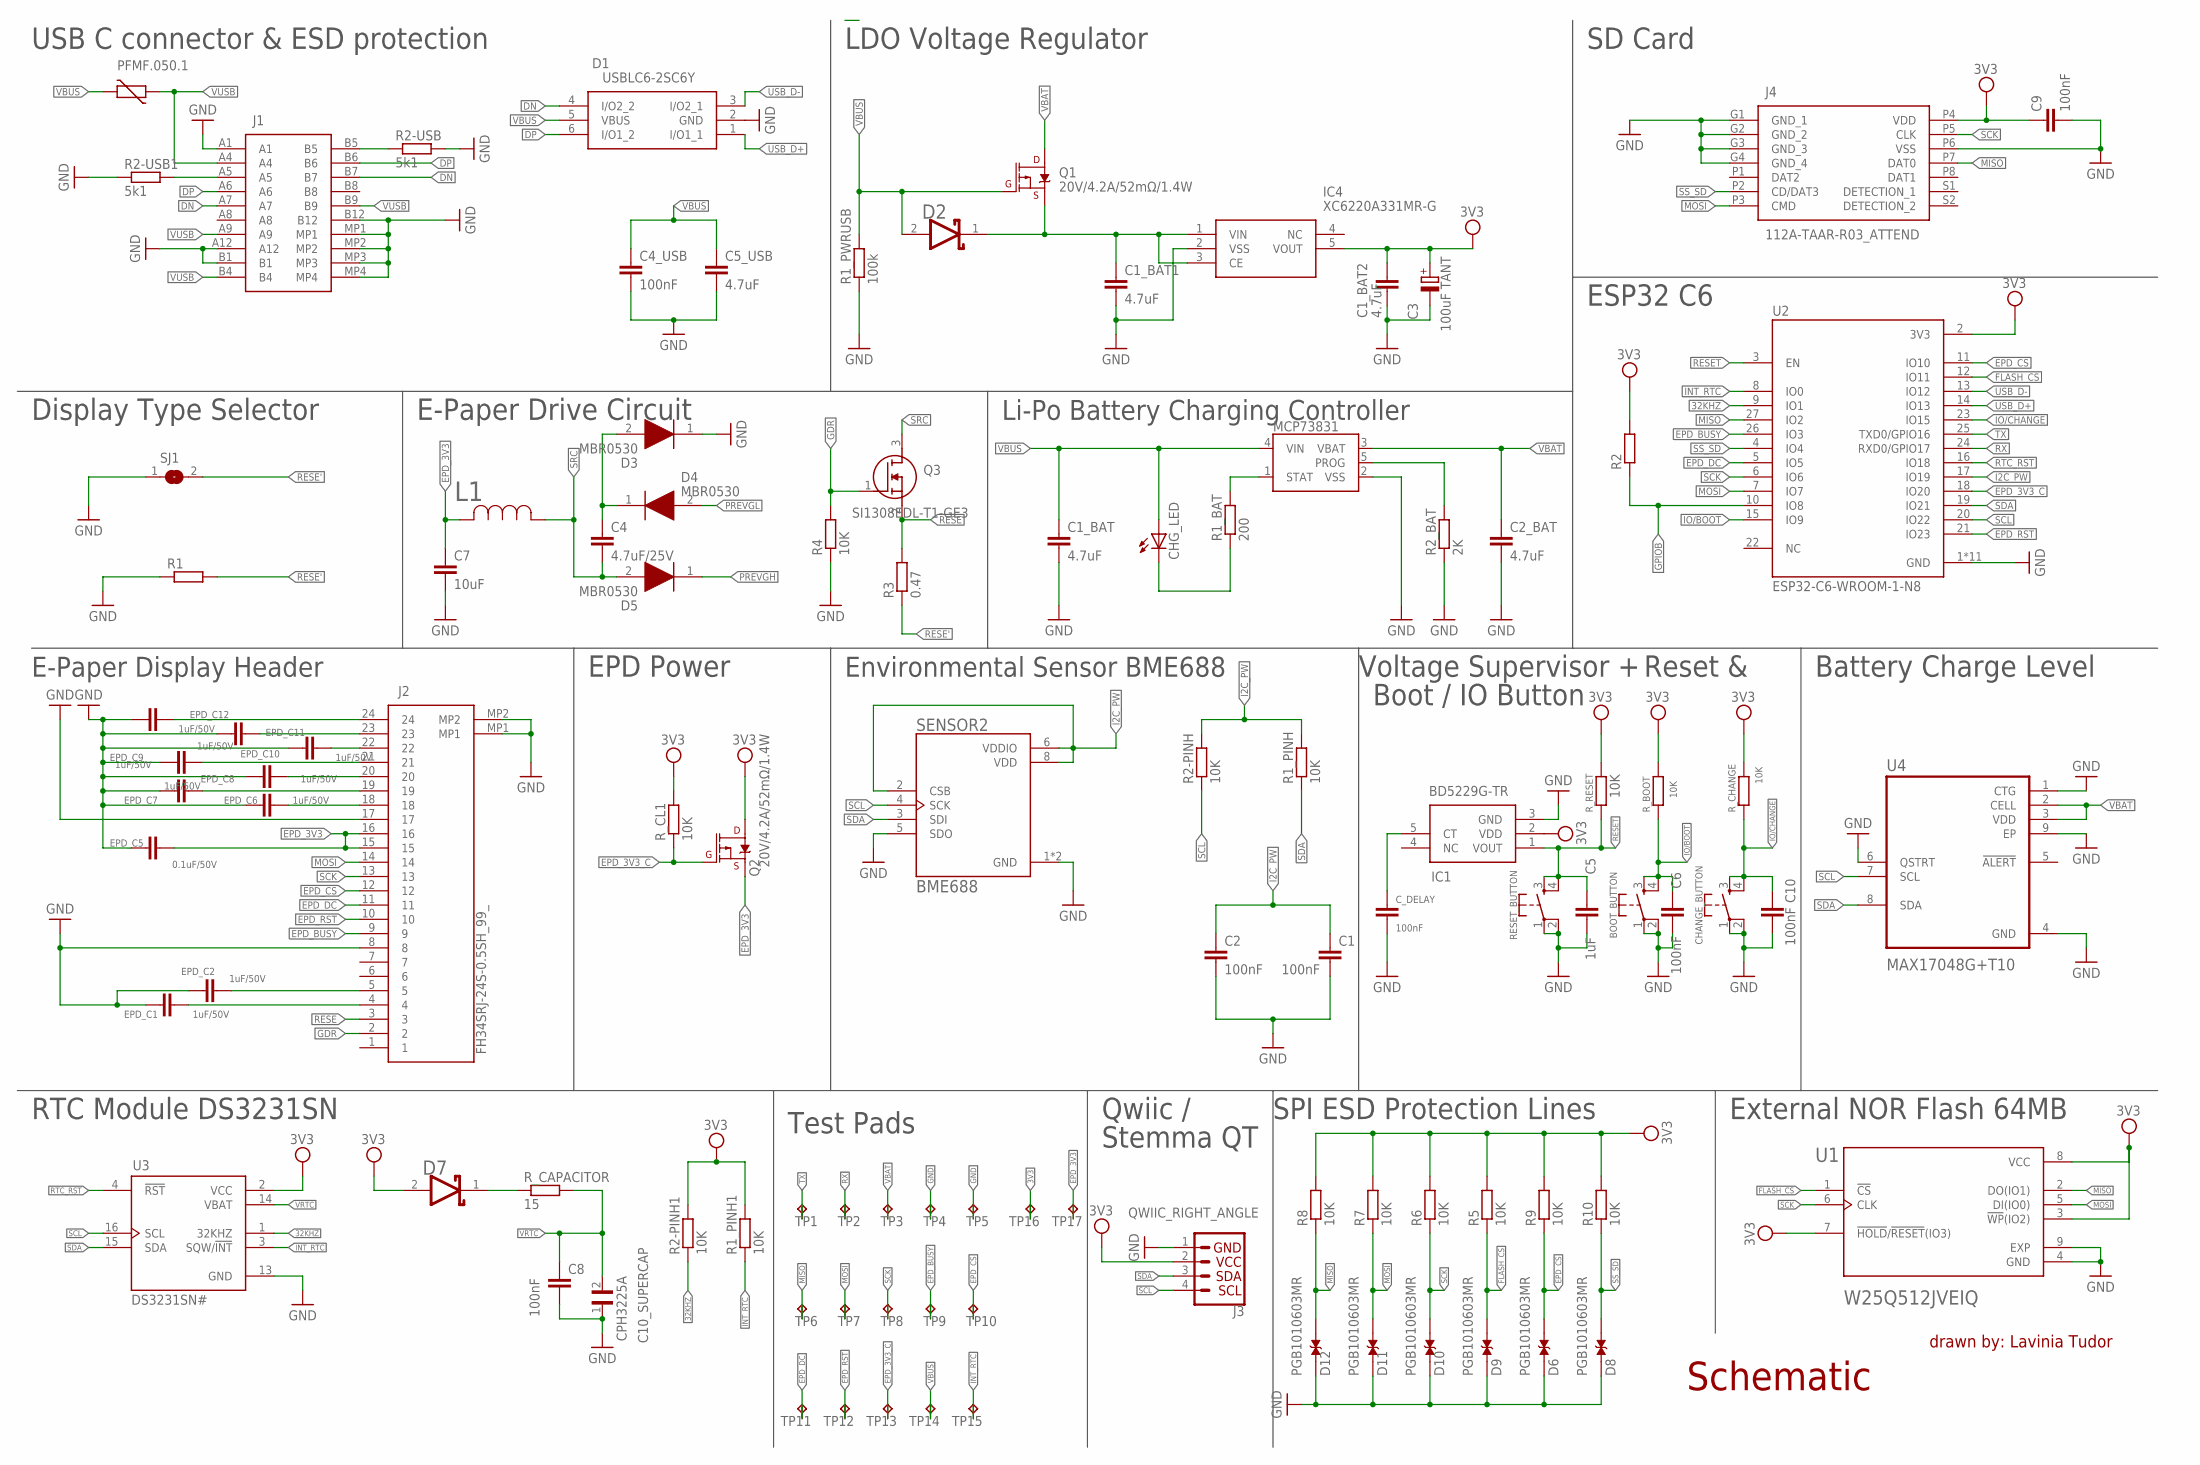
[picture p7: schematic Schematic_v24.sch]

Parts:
BOOT_BUTTON: BUTTON_CUSYOMV1; MYBUTTON
C1, C2, C6, C8, C10: 100nF; ESP32_WROVER_EAGLE-LTSPICE_C0402
C1_BAT, C1_BAT1, C1_BAT2, C2_BAT: 4.7uF; ESP32_WROVER_EAGLE-LTSPICE_C0402
C3: 100uF TANT; RCL_CT3528
C4: 4.7uF/25V; ESP32_WROVER_EAGLE-LTSPICE_C0402
C4_USB, C9: 100nF; EAGLE-LTSPICE_C0402
C5: 1uF; ESP32_WROVER_EAGLE-LTSPICE_C0402
C5_USB: 4.7uF; EAGLE-LTSPICE_C0402
C7: 10uF; ESP32_WROVER_EAGLE-LTSPICE_C0402
C10_SUPERCAP: CPH3225A; CAPCP3225X100N
CHANGE_BUTTON: BUTTON_CUSYOMV1; MYBUTTON
CHG_LED: ADAFRUIT_LEDCHIP-LED0603; ADAFRUIT_CHIP-LED0603
C_DELAY: 100nF; ESP32_WROVER_EAGLE-LTSPICE_C0402
D1: USBLC6-2SC6Y; SOT95P280X145-6N
D2, D7: ESP32_WROVER_AVX---SD0805S020S1R0_AVX_SD0805S020S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; ESP32_WROVER_AVX---SD0805S020S1R0_AVX_SD0805S020S1R0_0
D3, D4, D5: MBR0530; SOD3716X135N
D6, D8, D9, D10, D11, D12: PGB1010603MR; DIOC1608X36N
EPD_C1, EPD_C2, EPD_C6, EPD_C7, EPD_C8, EPD_C9, EPD_C10, EPD_C11, EPD_C12: 1uF/50V; ESP32_WROVER_EAGLE-LTSPICE_C0402
EPD_C5: 0.1uF/50V; ESP32_WROVER_EAGLE-LTSPICE_C0402
IC1: BD5229G-TR; SOT95P280X125-5N
IC4: XC6220A331MR-G; SOT95P280X120-5N
J1: SAMACSYS_PARTS_USB4110-GF-A; SAMACSYS_PARTS_USB4110GFA
J2: FH34SRJ-24S-0.5SH_99_; FH34SRJ24S05SH99
J3: QWIIC_RIGHT_ANGLE; JST04_1MM_RA
J4: 112A-TAAR-R03_ATTEND; 112ATAARR03ATTEND
L1: 744043680IND_4828-WE-TPC_WRE; IND_4828-WE-TPC_WRE
MCP73831: ESP32_WROVER_SPARKFUN-IC-POWER_MCP73831; ESP32_WROVER_SPARKFUN-IC-POWER_SOT23-5
PFMF.050.1: ESP32C6_VARISTORCN1812; ESP32C6_VARISTOR_CT/CN1812
Q1, Q2: 20V/4.2A/52mΩ/1.4W; ESP32_WROVER_SPARKFUN-DISCRETESEMI_SOT23-3
Q3: SI1308EDL-T1-GE3; SOT65P210X110-3N
R1, R2: ESP32_WROVER_EAGLE-LTSPICE_RR0402; ESP32_WROVER_EAGLE-LTSPICE_R0402
R1_BAT: 200; ESP32_WROVER_EAGLE-LTSPICE_R0402
R1_PINH, R1_PINH1, R2-PINH, R2-PINH1, R4, R5, R6, R7, R8, R9, R10: 10K; ESP32_WROVER_EAGLE-LTSPICE_R0402
R1_PWRUSB: 100k; ESP32_WROVER_EAGLE-LTSPICE_R0402
R2-USB, R2-USB1: 5k1; ESP32_WROVER_EAGLE-LTSPICE_R0402
R2_BAT: 2K; ESP32_WROVER_EAGLE-LTSPICE_R0402
R3: 0.47; ESP32_WROVER_EAGLE-LTSPICE_R0402
RESET_BUTTON: BUTTON_CUSYOMV1; MYBUTTON
R_BOOT: 10K; ESP32_WROVER_EAGLE-LTSPICE_R0402
R_CAPACITOR: 15; ESP32_WROVER_EAGLE-LTSPICE_R0402
R_CHANGE: 10K; ESP32_WROVER_EAGLE-LTSPICE_R0402
R_CL1: 10K; ESP32_WROVER_EAGLE-LTSPICE_R0402
R_RESET: 10K; ESP32_WROVER_EAGLE-LTSPICE_R0402
SENSOR2: BME688; ESP32_WROVER_BME680_PSON80P300X300X100-8N
SJ1: SJ
TP1, TP2, TP3, TP4, TP5, TP6, TP7, TP8, TP9, TP10, TP11, TP12, TP13, TP14, TP15, TP16, TP17: TPTP20R; TP20R
U1: W25Q512JVEIQ; SON127P600X800X80-9N
U2: ESP32-C6-WROOM-1-N8; XCVR_ESP32-C6-WROOM-1-N8
U3: DS3231SN#; SOIC127P1032X265-16N
U4: MAX17048G+T10; SON50P200X200X80-9N

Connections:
3V3: C1_BAT2.1, C3.+, C9.1, D7.2 (ANODE), IC1.2 (VDD), IC4.5 (VOUT), J3.2, J4.P4 (VDD), Q2.3 (D), R1_PINH1.2, R2.2, R2-PINH1.2, R5.2, R6.2, R7.2, R8.2, R9.2, R10.2, R_BOOT.2, R_CHANGE.2, R_CL1.2, R_RESET.2, TP16.TP, U1.3 (!WP!(IO2)), U1.7 (!HOLD!/!RESET!(IO3)), U1.8 (VCC), U2.2 (3V3), U3.2 (VCC)
32KHZ: R2-PINH1.1, U2.9 (IO1), U3.1 (32KHZ)
DN: D1.4 (I/O2_2), J1.A7, J1.B7
DP: D1.6 (I/O1_2), J1.A6, J1.B6
EPD_3V3: C7.1, EPD_C5.2, J2.15, J2.16, L1.2, Q2.2 (S), TP17.TP
EPD_3V3_C: Q2.1 (G), R_CL1.1, TP13.TP, U2.18 (IO20)
EPD_BUSY: J2.9, TP9.TP, U2.26 (IO3)
EPD_CS: D6.2, J2.12, R9.1, TP10.TP, U2.11 (IO10)
EPD_DC: J2.11, TP11.TP, U2.5 (IO5)
EPD_RST: J2.10, TP12.TP, U2.21 (IO23)
FLASH_CS: D9.2, R5.1, U1.1 (!CS), U2.12 (IO11)
GDR: J2.2, Q3.1 (G), R4.2
GND: BOOT_BUTTON.1, BOOT_BUTTON.2, C1.2, C1_BAT.2, C1_BAT1.2, C1_BAT2.2, C2.2, C2_BAT.2, C3.-, C4_USB.2, C5.2, C5_USB.2, C6.2, C7.2, C8.2, C9.2, C10.2, C10_SUPERCAP.1, CHANGE_BUTTON.1, CHANGE_BUTTON.2, C_DELAY.2, D1.2 (GND), D3.1 (K), D6.1, D8.1, D9.1, D10.1, D11.1, D12.1, EPD_C1.1, EPD_C2.1, EPD_C5.1, EPD_C6.1, EPD_C7.1, EPD_C8.1, EPD_C9.1, EPD_C10.1, EPD_C11.1, EPD_C12.1, IC1.3 (GND), IC4.2 (VSS), J1.A1, J1.A12, J1.B1, J1.B12, J1.MP1, J1.MP2, J1.MP3, J1.MP4, J2.8, J2.17, J2.MP1, J2.MP2, J3.1, J4.G1 (GND_1), J4.G2 (GND_2), J4.G3 (GND_3), J4.G4 (GND_4), J4.P6 (VSS), MCP73831.2 (VSS), R1.1, R1_PWRUSB.1, R2-USB.2, R2-USB1.1, R2_BAT.1, R4.1, RESET_BUTTON.1, RESET_BUTTON.2, SENSOR2.1 (GND), SENSOR2.5 (SDO), SENSOR2.7 (GND), SJ1.1, TP4.TP, TP5.TP, U1.4 (GND), U1.9 (EXP), U2.1 (GND), U2.28 (GND), U2.29_1 (GND), U2.29_2 (GND), U2.29_3 (GND), U2.29_4 (GND), U2.29_5 (GND), U2.29_6 (GND), U2.29_7 (GND), U2.29_8 (GND), U2.29_9 (GND), U3.13 (GND), U4.1 (CTG), U4.4 (GND), U4.6 (QSTRT), U4.9 (EP)
GPIOB: R2.1, U2.10 (IO8)
I2C_PW: C1.1, C2.1, R1_PINH.2, R2-PINH.2, SENSOR2.2 (CSB), SENSOR2.6 (VDDIO), SENSOR2.8 (VDD), U2.17 (IO19)
INT_RTC: R1_PINH1.1, TP15.TP, U2.8 (IO0), U3.3 (SQW/!INT)
IO/BOOT: BOOT_BUTTON.3, BOOT_BUTTON.4, C6.1, R_BOOT.1, U2.15 (IO9)
IO/CHANGE: C10.1, CHANGE_BUTTON.3, CHANGE_BUTTON.4, R_CHANGE.1, U2.23 (IO15)
MISO: D12.2, J4.P7 (DAT0), R8.1, TP6.TP, U1.2 (DO(IO1)), U2.27 (IO2)
MOSI: D11.2, J2.14, J4.P3 (CMD), R7.1, TP7.TP, U1.5 (DI(IO0)), U2.7 (IO7)
unnamed: C1_BAT1.1, D2.1 (CATHODE), IC4.1 (VIN), IC4.3 (CE), Q1.2 (S)
unnamed: J1.A5, R2-USB1.2
unnamed: J1.B5, R2-USB.1
unnamed: C4.1, D3.2 (A), D4.1 (K)
unnamed: EPD_C12.2, J2.24
unnamed: CHG_LED.C, R1_BAT.1
unnamed: MCP73831.1 (STAT), R1_BAT.2
unnamed: MCP73831.5 (PROG), R2_BAT.2
unnamed: EPD_C11.2, J2.23
unnamed: EPD_C10.2, J2.22
unnamed: EPD_C9.2, J2.21
unnamed: EPD_C8.2, J2.20
unnamed: EPD_C7.2, J2.19
unnamed: EPD_C6.2, J2.18
unnamed: C_DELAY.1, IC1.5 (CT)
unnamed: EPD_C2.2, J2.5
unnamed: D7.1 (CATHODE), R_CAPACITOR.1
unnamed: EPD_C1.2, J2.4
PREVGH: D5.1 (K)
PREVGL: D4.2 (A)
RESE: J2.3, Q3.2 (S), R3.2
RESE': R1.2, R3.1, SJ1.2
RESET: C5.1, IC1.1 (VOUT), RESET_BUTTON.3, RESET_BUTTON.4, R_RESET.1, U2.3 (EN)
RTC_RST: U2.16 (IO18), U3.4 (!RST)
RX: TP2.TP, U2.24 (RXD0/GPIO17)
SCK: D10.2, J2.13, J4.P5 (CLK), R6.1, TP8.TP, U1.6 (CLK), U2.6 (IO6)
SCL: J3.4, R2-PINH.1, SENSOR2.4 (SCK), U2.20 (IO22), U3.16 (SCL), U4.7 (SCL)
SDA: J3.3, R1_PINH.1, SENSOR2.3 (SDI), U2.19 (IO21), U3.15 (SDA), U4.8 (SDA)
SRC: C4.2, D5.2 (A), L1.1, Q3.3 (D)
SS_SD: D8.2, J4.P2 (CD/DAT3), R10.1, U2.4 (IO4)
TX: TP1.TP, U2.25 (TXD0/GPIO16)
USB_D+: D1.1 (I/O1_1), U2.14 (IO13)
USB_D-: D1.3 (I/O2_1), U2.13 (IO12)
VBAT: C2_BAT.1, MCP73831.3 (VBAT), Q1.3 (D), TP3.TP, U4.2 (CELL), U4.3 (VDD)
VBUS: C1_BAT.1, C4_USB.1, C5_USB.1, CHG_LED.A, D1.5 (VBUS), D2.2 (ANODE), MCP73831.4 (VIN), PFMF.050.1.2, Q1.1 (G), R1_PWRUSB.2, TP14.TP
VRTC: C8.1, C10_SUPERCAP.2, R_CAPACITOR.2, U3.14 (VBAT)
VUSB: J1.A4, J1.A9, J1.B4, J1.B9, PFMF.050.1.1

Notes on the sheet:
drawn by: Lavinia Tudor
Schematic
USB C connector & ESD protection
LDO Voltage Regulator
Display Type Selector
E-Paper Drive Circuit
SD Card
ESP32 C6
Battery Charge Level
Voltage Supervisor +
Reset &
Boot / IO Button
Environmental Sensor BME688
EPD Power
E-Paper Display Header
Li-Po Battery Charging Controller
RTC Module DS3231SN
Test Pads
Qwiic /
Stemma QT
SPI ESD Protection Lines
External NOR Flash 64MB

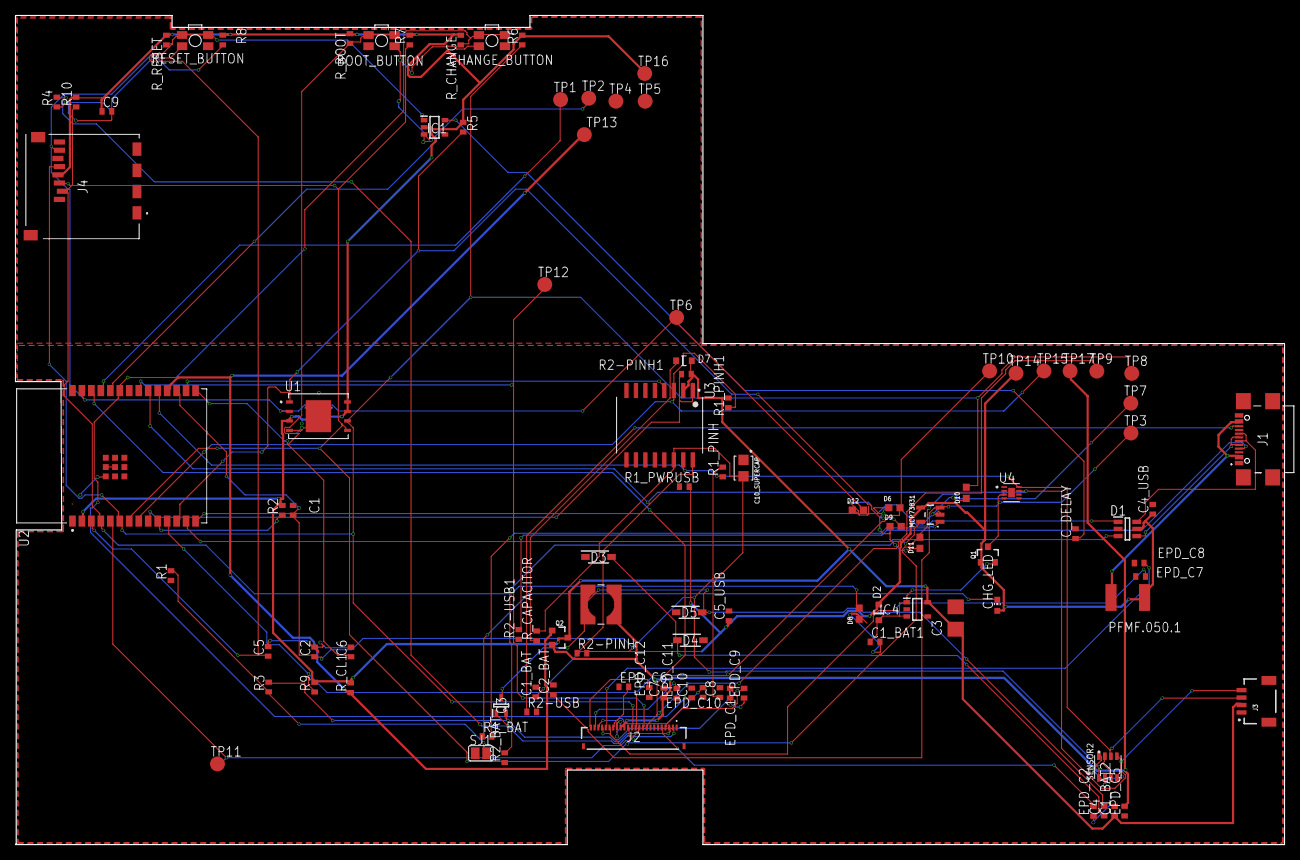
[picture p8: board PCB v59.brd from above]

Board: 2 copper layers, 170.2 x 111.2 mm, 103 parts (0 on the bottom side), 55 nets.

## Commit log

2025-03-30 Am terminat schematicul
2025-03-31 Am reparat eroarea din Schematic
2025-04-06 varianta pcb_25 de fire galbene ramase
2025-04-06 au mai ramas 13 erori la pcb
2025-04-06 Gata cu pcb-ul
2025-04-06 Am exportat fisierele Gerber si Assembly
    [copper_bottom.gbr, copper_top.gbr, gerber_job.gbrjob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]
2025-04-06 Am creat structura ptr git ca in enunt
    [copper_bottom.gbr, copper_top.gbr, gerber_job.gbrjob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]
2025-04-06 Ne apropiem de final
    [PCB v34.xlsx, PnP_PCB v34_front.csv]
2025-04-13 Schematic salvat in forma .sch si pcb cu reparatiile facute sub forma .brd
    [PCB v59.brd, Schematic_v24.sch]
2025-04-14 Manufacturing - reparat
    [PCB v34.xlsx, PCB_v67.bom.csv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]
2025-04-14 Manufacturing - reparat - am schimbat numele
    [PCB_v67.csv, PnP_PCB_v67_front.csv]

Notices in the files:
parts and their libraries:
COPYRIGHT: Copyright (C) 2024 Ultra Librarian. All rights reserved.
